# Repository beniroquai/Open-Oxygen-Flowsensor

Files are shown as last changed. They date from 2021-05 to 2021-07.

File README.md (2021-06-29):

# Open Oxygen (O2) Flow Sensor

**WORK IN PROGRESS - more information will follow soon!**

This device is supposed to measure the oxygen flowrate of oxygen bottles.
We would like to have an open-source solution for something like the [TSI digital oxygen flow sensor](https://tsi.com/produkte/durchflussmesser,-durchflusssensoren-testsysteme/die-neuen-digitalen-durchflussmesser-serie-5000/).

<p align="center">
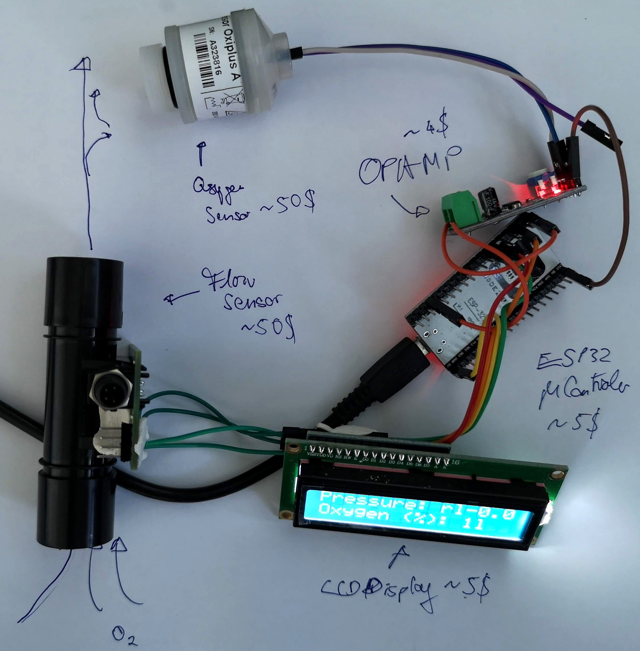
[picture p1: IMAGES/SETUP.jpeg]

</p>

***Features:***

- Open-Source
- Low-Cost (~150€)
- Based on 3D parts + off-the-shelf components
- Minimum of tools required
- Portable by relying on a USB power bank
- LCD for displying oxygen level and flowrate

# Electronics

The flowsensor and the display are connected to the ESP32 via I2C (GPIO 21/22 for SDA/SCL), wheras the Oxygen Sensor is connected to the board via an ampliefied (i.e. OPAMP) digital-analog port.

<p align="center">
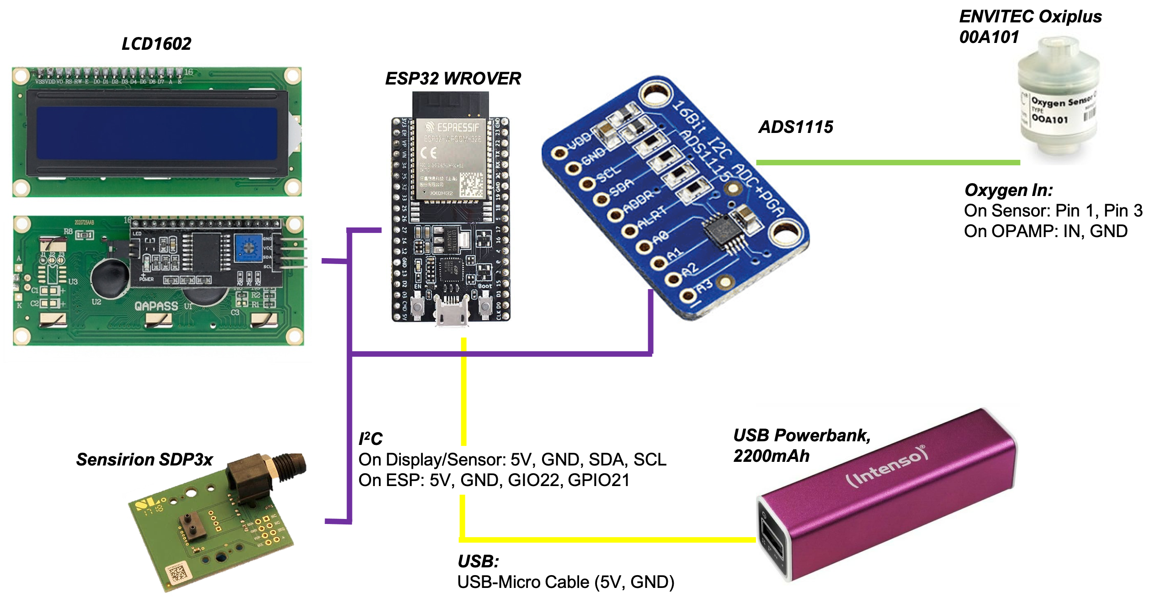
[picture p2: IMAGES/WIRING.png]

</p>

***WARNING:*** The OPAMP has a high-pass filter created by a capacitor + resistor. We need to remove this to let the low-frequency signal from the Oxygen Sensor pass through.

***Solution:*** Instead of relying on the internal ADC converter and have a rather unknwon OPAMP, we decided to go for digital-ADC with a dedicated I2C interface. 
The ADS1115 has 4 channels and a resolution of 16 Bit. 

<p align="center">

</p>

In order to make the device independent from external energy sources, we incorporate a USB-battery/powersupply. We rely on a widely available form factor, where the brand/name of the device can largely vary. 

***Explenation for the ADS1115:*** *Differential* or *Single Ended* use? We have a positive DC-signal in the range of `0...~100mV`, hence we can go for the single-mode use. An in-depth explanation can be found at [Adafruit](https://learn.adafruit.com/adafruit-4-channel-adc-breakouts/signal-connections). The oxygen sensor is then connected to `Pin+ => AD0` and `Pin- => GND`. Running the test-script on the ESP32 should give you a voltage of `13mV` in air. 

# CAD Files

The parts were designed in Autodesk Inventor 2019 student edition and can be found in the folder [./CAD](CAD)
An enclosure/box to keep all parts in place will be 3D printable.

<p align="center">
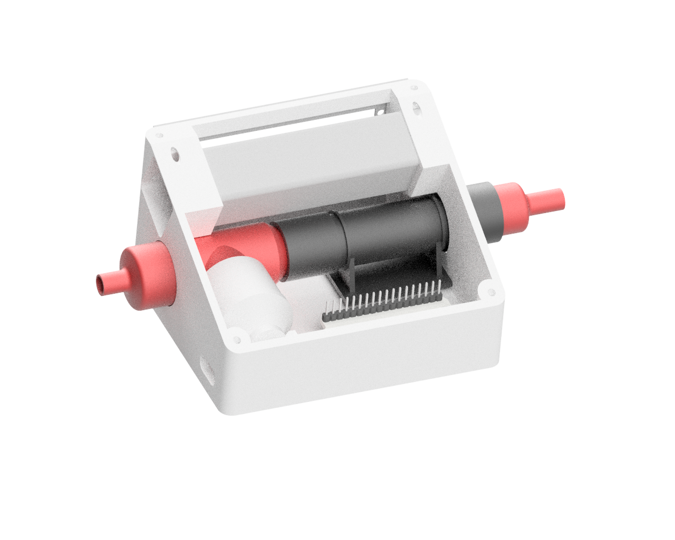
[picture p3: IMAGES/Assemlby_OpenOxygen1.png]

</p>

*Arrangement of all the parts*

## Housing for the setup

The setup will have a housing for all the parts. Currently it looks like this, where the battery is sitting on top:

<p align="center">
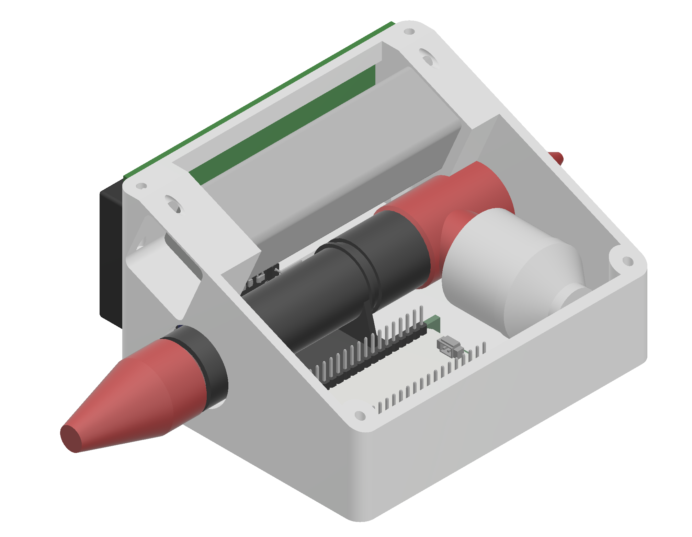
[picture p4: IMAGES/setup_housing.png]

</p>

*Arrangement of all the parts*

<p align="center">
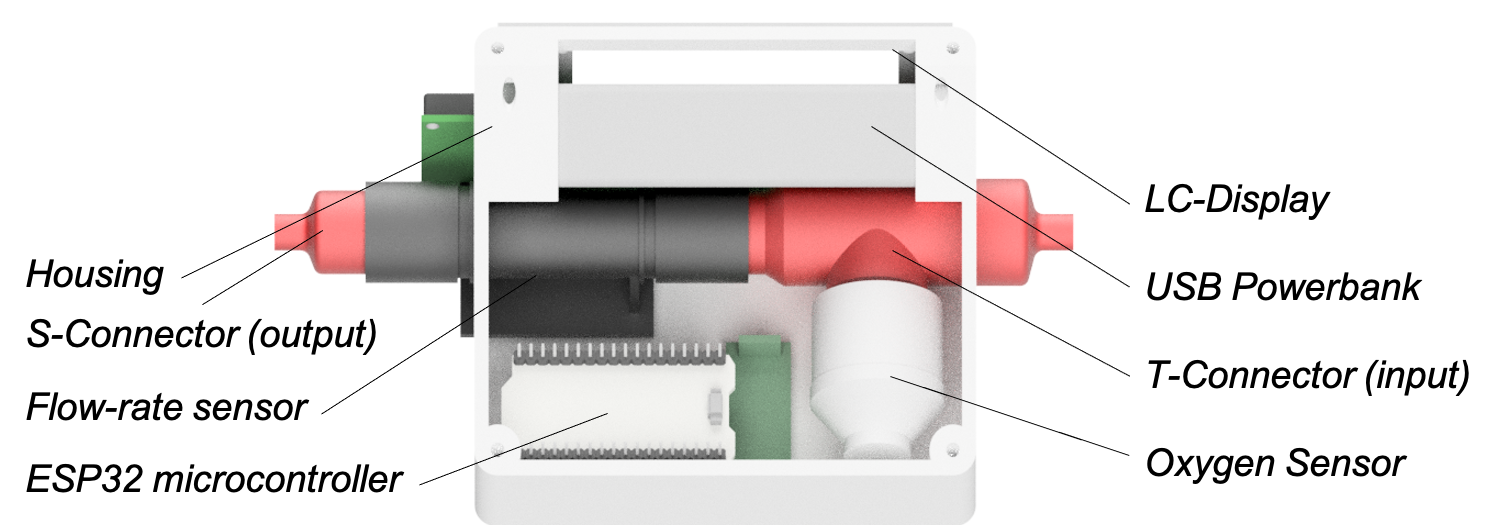
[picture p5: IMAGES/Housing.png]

</p>

All **3D printable** files can be found in [./STL](./STL)

# Assembly

*Sorry for the confusion:* You can mount the parts in both directions. Here, the CAD rendering shows the oxygen sensor on the right hand side, whereas the printed version shows it on the right hand side. Either way works!

1. Make sure you solder all parts together according to the wiring diagram above; To keep the wire chaos small: Twist the cables to form wire bundles; Test its proper functionality by e.g. running the [I2C scanner in the Arduino IDE](https://playground.arduino.cc/Main/I2cScanner/) (you must detect 3 addresses); Then flash the firmware in the Arduino folder.  ***HINT:*** There are some libraries involved; Please install them from the library downloader menu as described [here](https://www.arduino.cc/en/guide/libraries). The following libraries are used: `LiquidCrystal_I2C by Brabander`, `Sparkfun SDP3X by Sparkfun`, and `Adafruit ADS1X15`.
2. Place the LCD screen on the front plate and mount it with 4 M3x12 screws 
3. Place the flow-rate sensor (sensirion) on the plate by pushing one end through one of the wholes. Watch the photograph:

<p align="center">
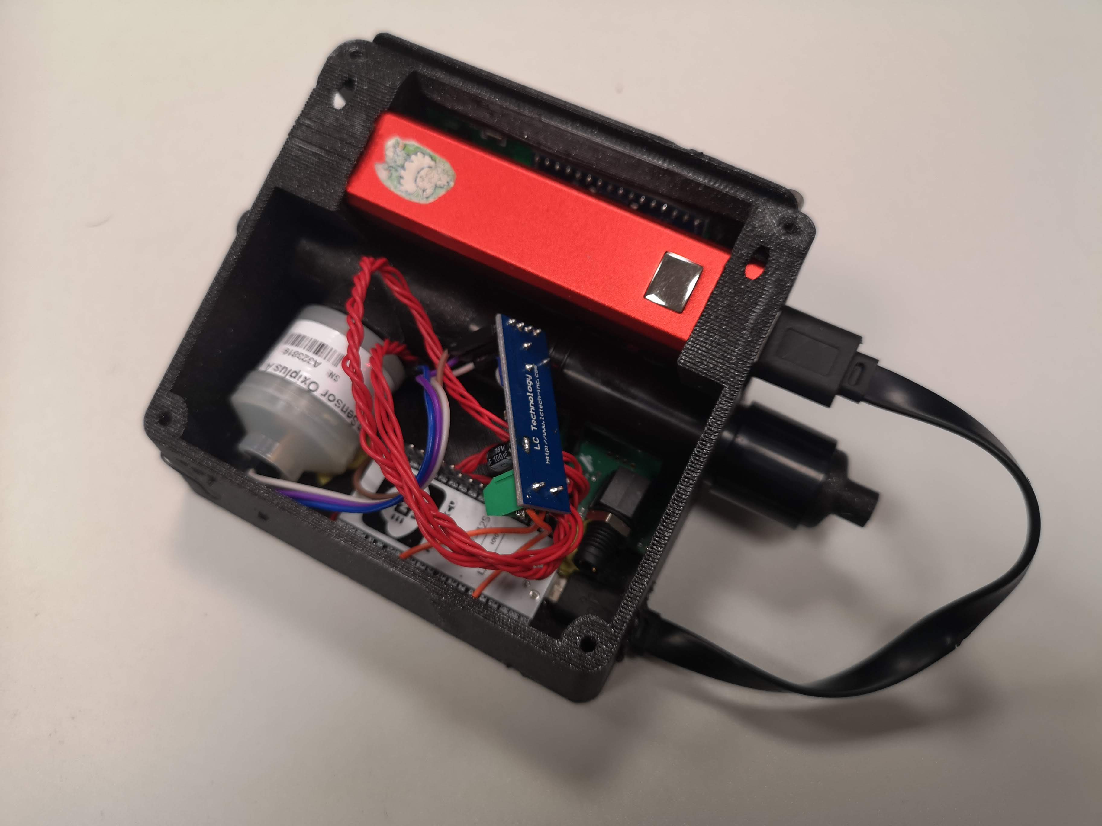
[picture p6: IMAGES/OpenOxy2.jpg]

</p>

4. Now mount the S-connector to the outside of the injection moulded flow adapter (black plastic part of the sensirion); Beware: We don't mount the flow sensor permanently 
5. Mount the T-connector (tricky part, not much space); push the black flow adaptor at a side (e.g. diagonal) and try sneaking in the T-adaptor; Move the one thin end into the hole of the Flow sensor
6. Mount the Oxygen sensor to the open end of the T-connector inside the case 
7. Rotate the oxygen sensor the way that it resides on the base plate 
8. Place the ESP32 in the free spot on the base (no holes for screws, since the formfactor is largely varying!) 
9. Place the OPAMP in the assembly; make sure the open pin connects will **never** cause any shortcut!
10. Mount the LCD Screen using additional M3 screws:

<p align="center">
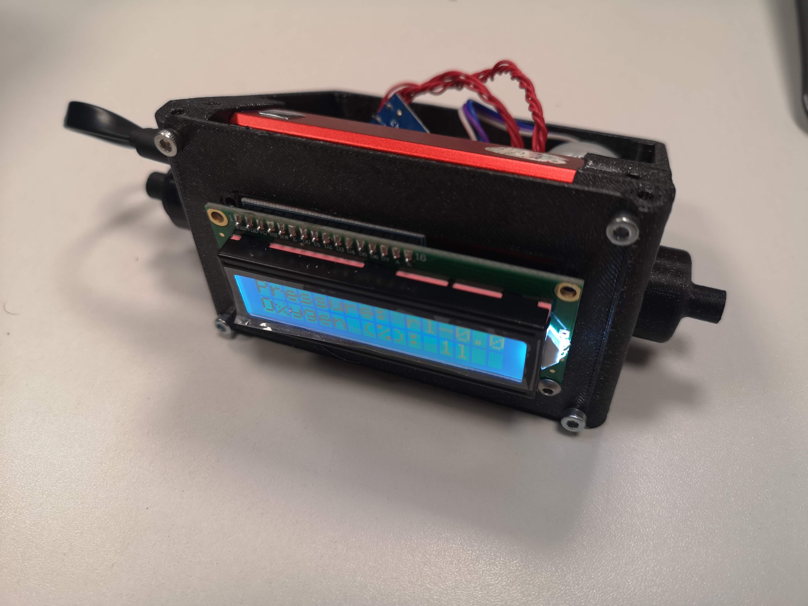
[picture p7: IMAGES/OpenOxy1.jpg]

</p>

11. Add the Powerbank in the desired slot and also add the USB Micro cable
<p align="center">
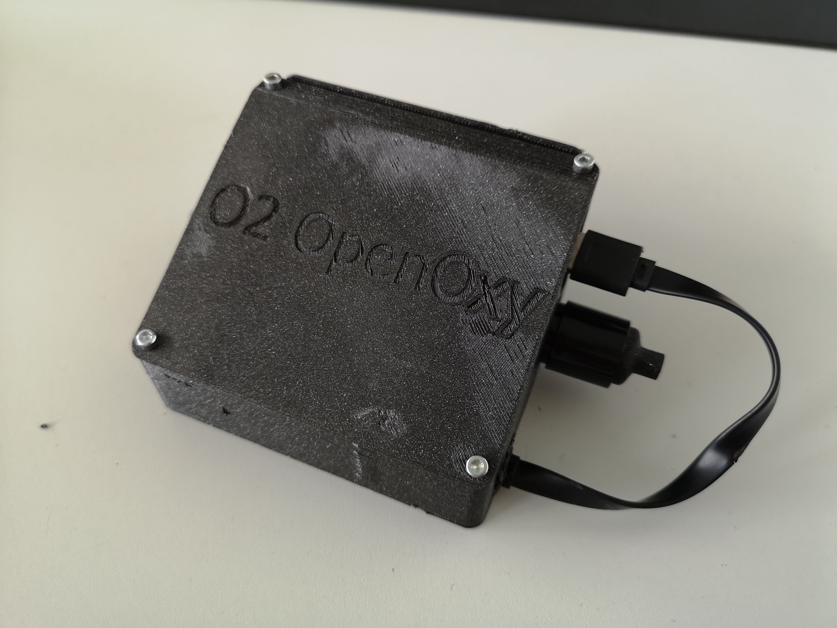
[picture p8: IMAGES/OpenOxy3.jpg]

</p>

12. Add the lid and mount it using M3 screws 
<p align="center">
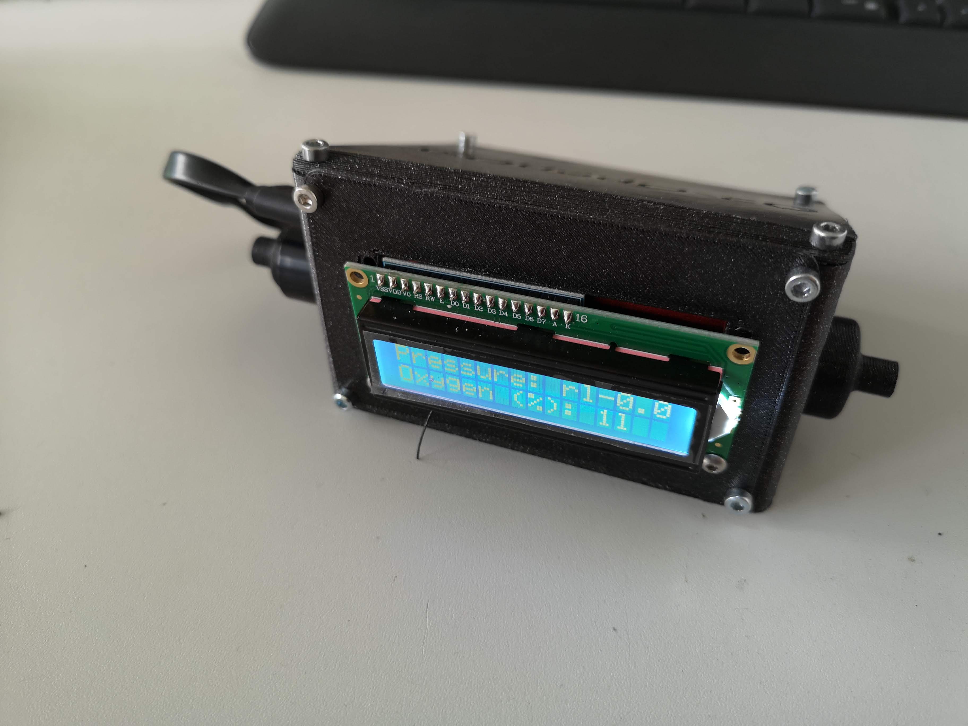
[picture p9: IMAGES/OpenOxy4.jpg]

</p>

13. You are done! If you want to have the assembly working under an anble, you can simply rotate the screen: 

<p align="center">
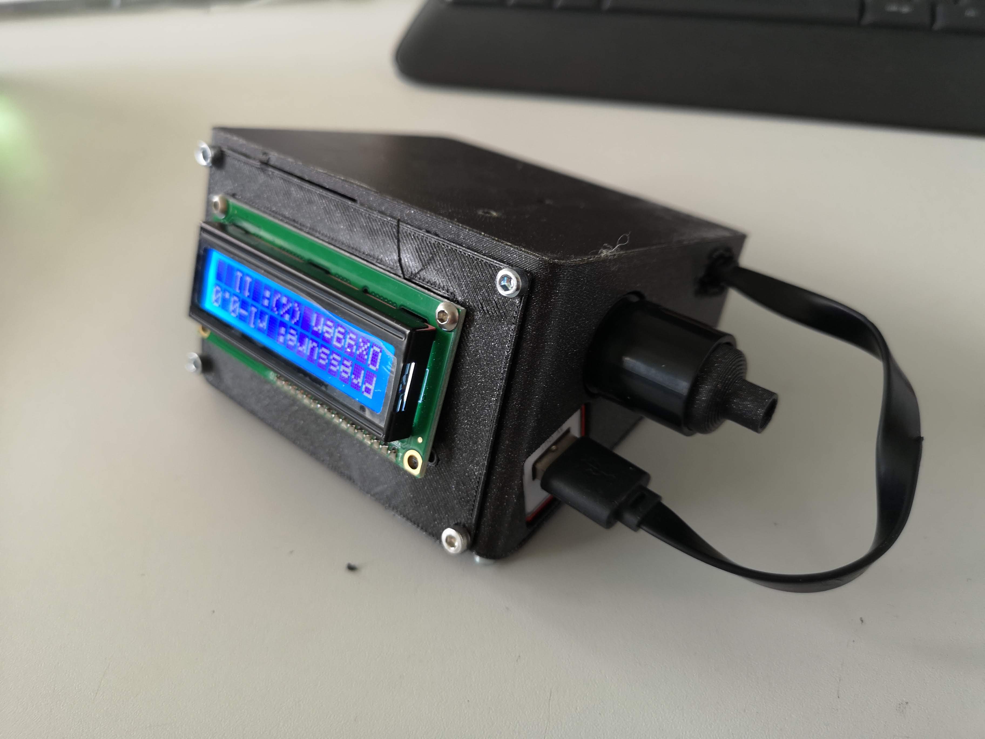
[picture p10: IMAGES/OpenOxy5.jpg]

</p>

# Software

A first attempt to connect all components can be found in [./ARDUINO](./ARDUINO) (even though it's used by an ESP32, flash it in the Arduino IDE).

## Calibration

### Calibration of the air flow

The [datasheet](Sensirion_Differential_Pressure_AppNotes_EK-P4_Flow_Element.pdf) for the Sensirion EK-P4 Evaluation Kit
For SDP3x Flow sensor suggests a relationship between differential pressure and flow-rate measured in Standard Liters per Minute (slm). We fit a curve to the values given in the application note in order to have a parametrized function for the digital readout:

<p align="center">
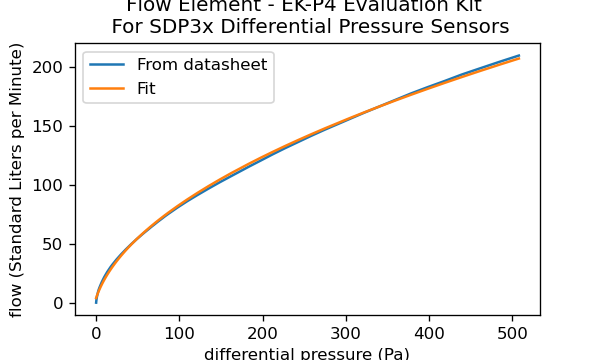
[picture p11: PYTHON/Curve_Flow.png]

</p>

The corresponding Python script to generate this figure can be found [here](PYTHON/Fit_Flow_Calibration_Function.py). 

The fit suggest the following function: 

```py
def func(x, a, b, c, d):
    return a+np.sqrt(b+x*d)*c

a=-20.04843438
b=59.52168936
c=3.11050553
d=10.35186327
```

which can easily be implemented on the ESP32. 

Use previously measured calibration data? 

### Calibration of the oxygen level (automatic)

By default, the current implementation will automatically calibrate the initial voltage of the oxygen sensor to correspond to 20.9% O2 level. This calibration will take place 10 seconds after starting the device.

### Calibration of the oxygen level (manual)

The oxygen sensor has a voltage of ~11mV in air, coresopnding to 20.9% O2 level. Placing the whole device in a oxygen-free enivornment (e.g. dry ice), gives a signal from ~3mV. This information can be used to fit a curve and compute the parameters for the linear fit (~3% error according to the manual/datasheet). 

<p align="center">
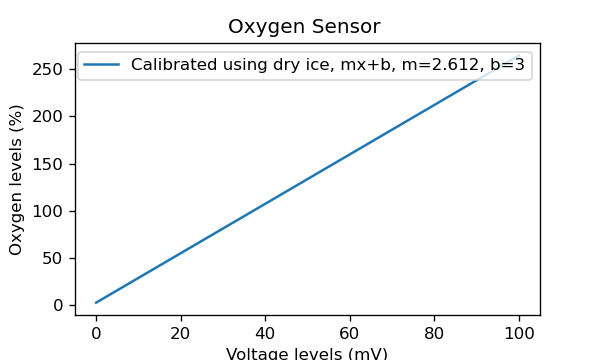
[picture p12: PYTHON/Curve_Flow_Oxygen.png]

</p>

The corresponding Python script to generate this figure can be found [here](PYTHON/Fit_Flow_Calibration_Function.py) and gives these values:
```py
m,b
2.6125 3
```

which have to be entered in the code `OpenOxygenFlowMeter.ino` in the folder [ARDUINO](./ARDUINO)
```cpp
float oxy_m = 2.62; // needs to be calibrated
float oxy_b = 3;  // needs to be calibrated (corresponds to the voltage at Oxygen level == 0%)
```

In order to prevent `oxy_m` from being auto calibrated, automatic calibration needs to be disabled by setting `boolean shouldDoWarmupCalibration = false;`.

# Bill of materials

- Misc Wires for connecting all parts (use proper soldered connection!)
- USB micro Cable for flashing the firmware and for supplying energy for portable-mode
- Various M3 Cylindrical Screws, M3x12mm, 1€ 
- [I2C LCD Display](https://de.aliexpress.com/item/32413056677.html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,searchweb201602_,searchweb201603_), **1,82€**
- [ads1115 Analog Digital Converter, 16Bit, I2C Breakoutboard](https://de.aliexpress.com/item/32584944400.html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) (Need to be tested); **2,32€**
- [ESP32](https://de.aliexpress.com/item/1005002624723822.html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,searchweb201602_,searchweb201603_), **4,01€**
- [oxygen sensor oxiplus a 00a101](https://de.aliexpress.com/item/4000133941125.html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,searchweb201602_,searchweb201603_); **50,01€**, [Datasheet](https://www.was-geisler.biz/WEBSERVER/Bausteine/Dateien/DB_AU-007_008.pdf)
- [Sensirion Evaluationskit EK-P4, SDP3X](https://www.digikey.de/product-detail/de/sensirion-ag/EK-P4/1649-1059-ND/6109354?productid=6109354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); **50,10€**, [Datasheet](https://www.sensirion.com/en/flow-sensors/differential-pressure-sensors/test-your-sdp3x-differential-pressure-sensor-with-the-evaluation-kit-ek-p4/)
- [USB Powerbank, 5V, 2200mAh (make sure, the battery looks like the one above!)](https://www.ebay.de/p/1437454225); **2,10€**, The brand can vary, but make sure it's fitting in the housing)

# Contribute
If you have a question or found an error, please file an issue! We are happy to improve the device!

# License
Please have a look into the dedicated License file.

# Disclaimer
We do not give any guarantee for the proposed setup. Please use it at your own risk. Keep in mind that Laser source can be very harmful to your eye and your environemnt! It is not supposed to be used as a medical device!

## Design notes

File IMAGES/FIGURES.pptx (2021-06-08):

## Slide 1

LCD1602

ENVITEC Oxiplus
00A101

Oxygen In:
On Sensor: Pin 1, Pin 3
On OPAMP: IN, GND

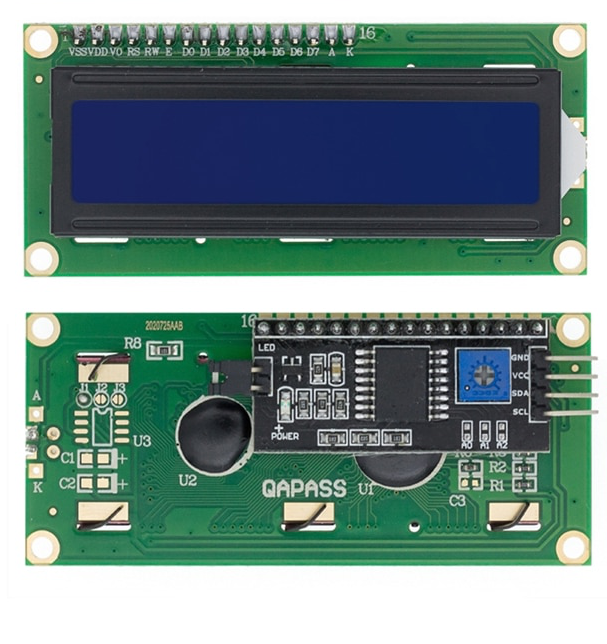
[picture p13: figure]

ESP32 WROVER

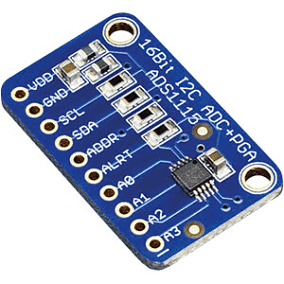
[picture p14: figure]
Entwicklerboards - A/D-Verstärker-Platine, 16-Bit, ADS1115 - DEBO AMP 16BIT
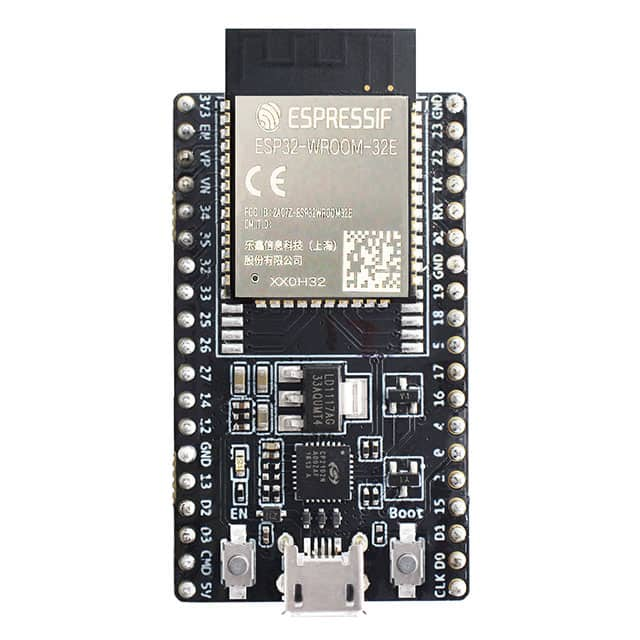
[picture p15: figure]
ESP32-DEVKITC-32E Espressif Systems | HF/ZF und RFID | DigiKey

ADS1115

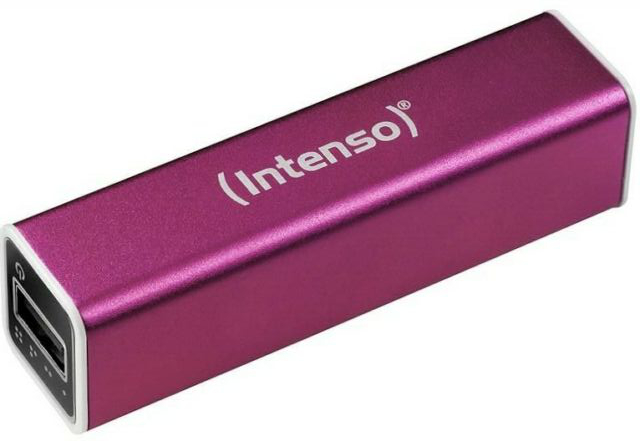
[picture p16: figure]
Bild 3 von 4

USB Powerbank,
2200mAh

Sensirion SDP3x

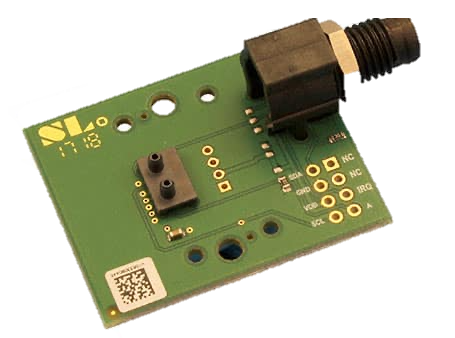
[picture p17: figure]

I²C
On Display/Sensor: 5V, GND, SDA, SCL
On ESP: 5V, GND, GIO22, GPIO21

USB:
USB-Micro Cable (5V, GND)

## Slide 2

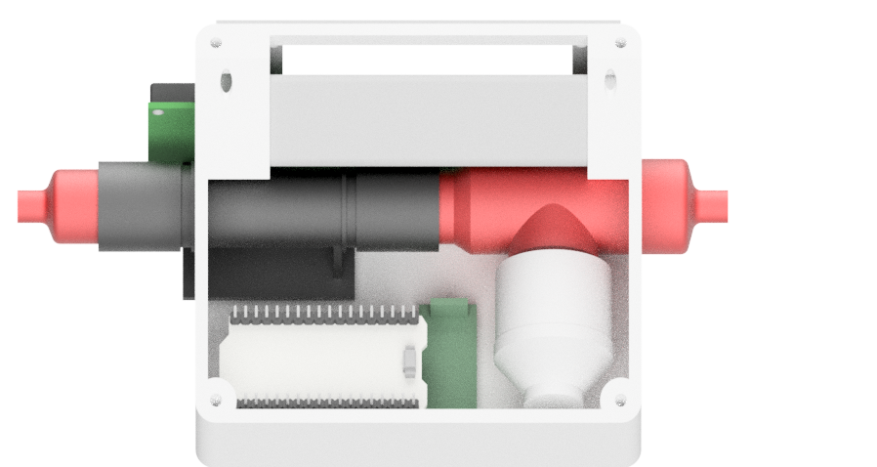
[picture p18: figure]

Housing

LC-Display

USB Powerbank

S-Connector (output)

T-Connector (input)

Flow-rate sensor

ESP32 microcontroller

Oxygen Sensor

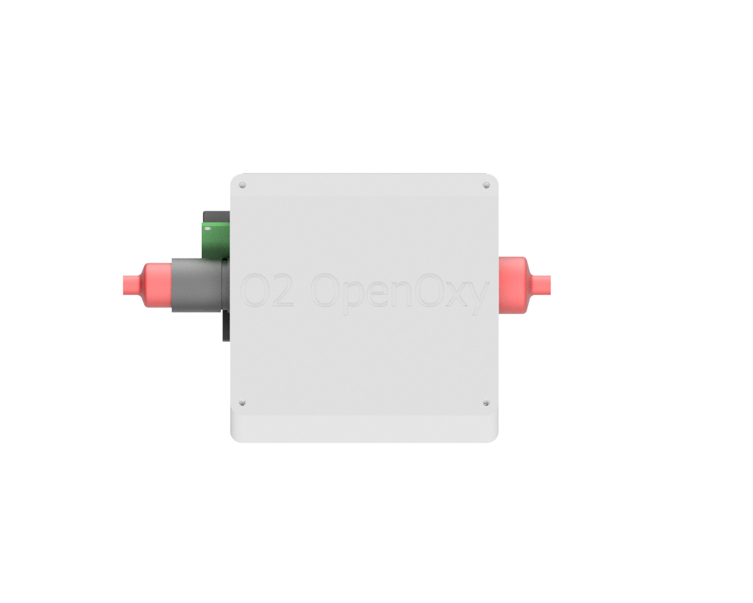
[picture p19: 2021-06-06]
IMAGES/Assemlby_OpenOxygen.png

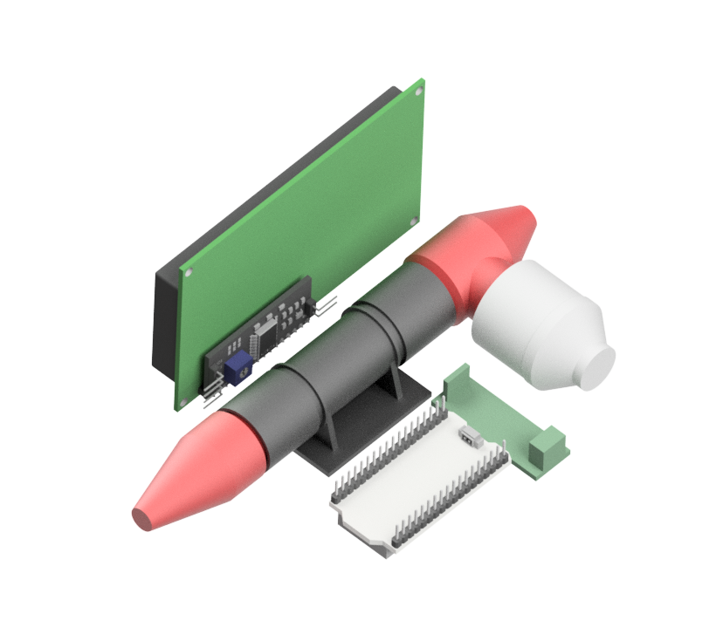
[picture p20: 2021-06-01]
IMAGES/image.png

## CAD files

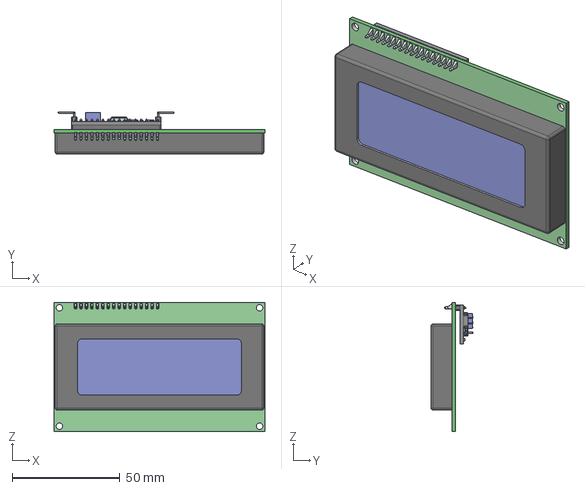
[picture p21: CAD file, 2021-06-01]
INVENTOR/00_Arduino_LCD_I2Cstep.step
98.0 x 19.6 x 60.0 mm

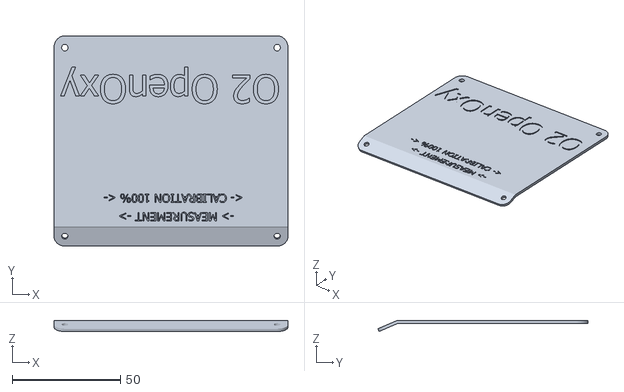
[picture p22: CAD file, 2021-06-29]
STL/Assemlby_OpenOxygen_02_03_Lid.stl
108.0 x 97.0 x 5.08

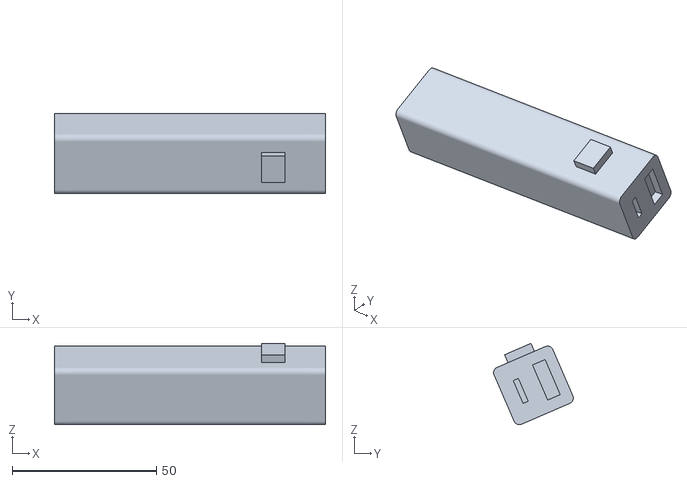
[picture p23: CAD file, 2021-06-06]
STL/NON-printable/Assemlby_OpenOxygen_00_Batterypack.stl
94.0 x 27.7 x 28.2

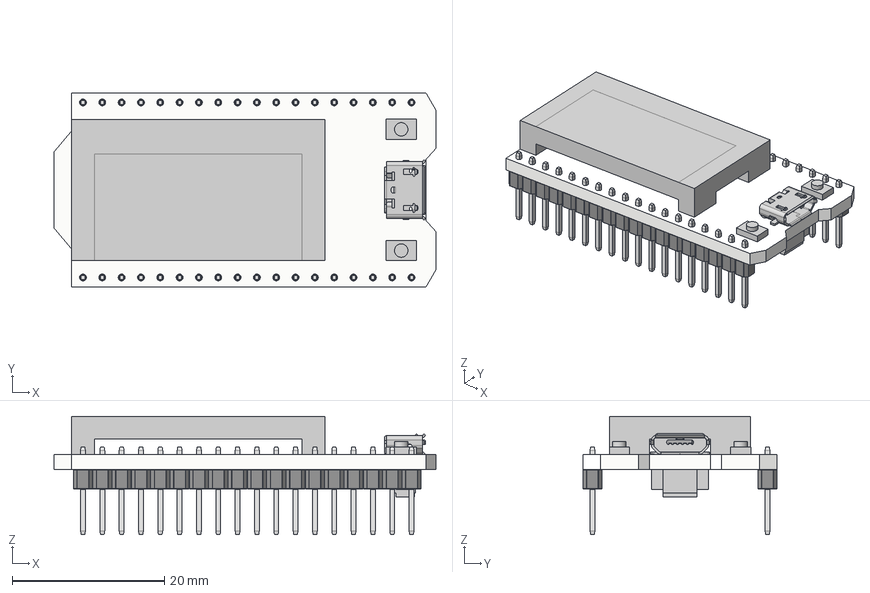
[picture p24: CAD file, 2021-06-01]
INVENTOR/00_ESP32.step
50.2 x 25.5 x 15.5 mm
Micro-USB Cable socket
SH1.25-2
1 Pin 2.54 Header x 36

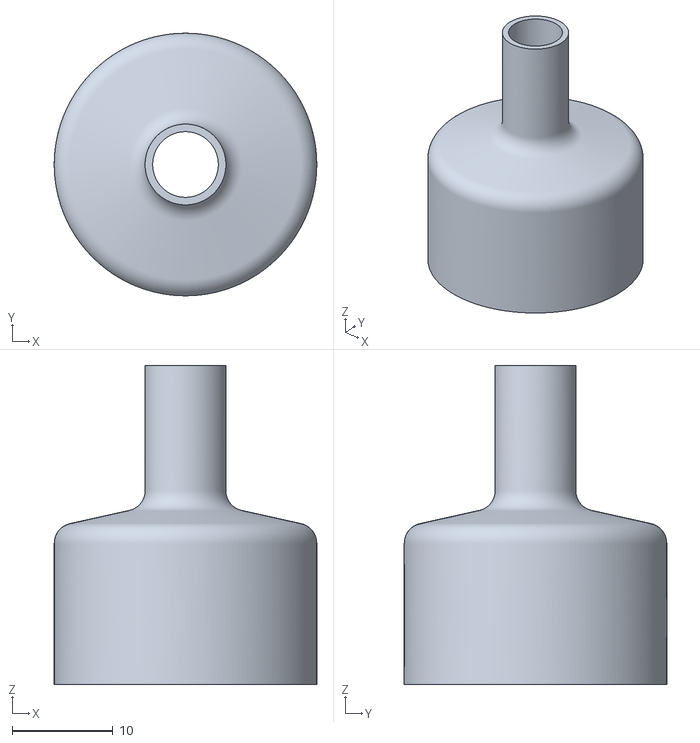
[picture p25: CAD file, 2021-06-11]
STL/Assemlby_OpenOxygen_02_Connector_S.stl
26.0 x 26.0 x 31.6

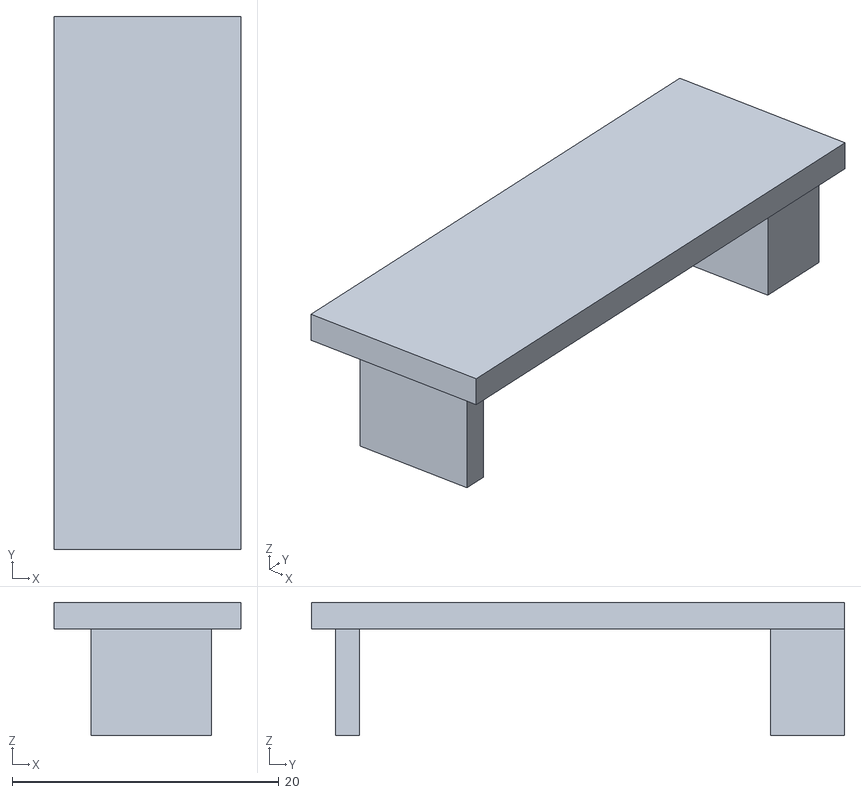
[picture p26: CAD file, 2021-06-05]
STL/NON-printable/Assemlby_OpenOxygen_00_LM286.stl
14.0 x 40.0 x 10.0

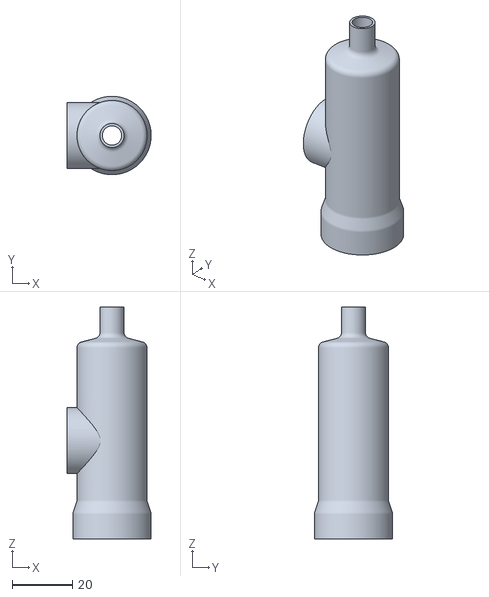
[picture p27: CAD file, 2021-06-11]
STL/Assemlby_OpenOxygen_02_Connector_T.stl
28.0 x 26.0 x 77.0

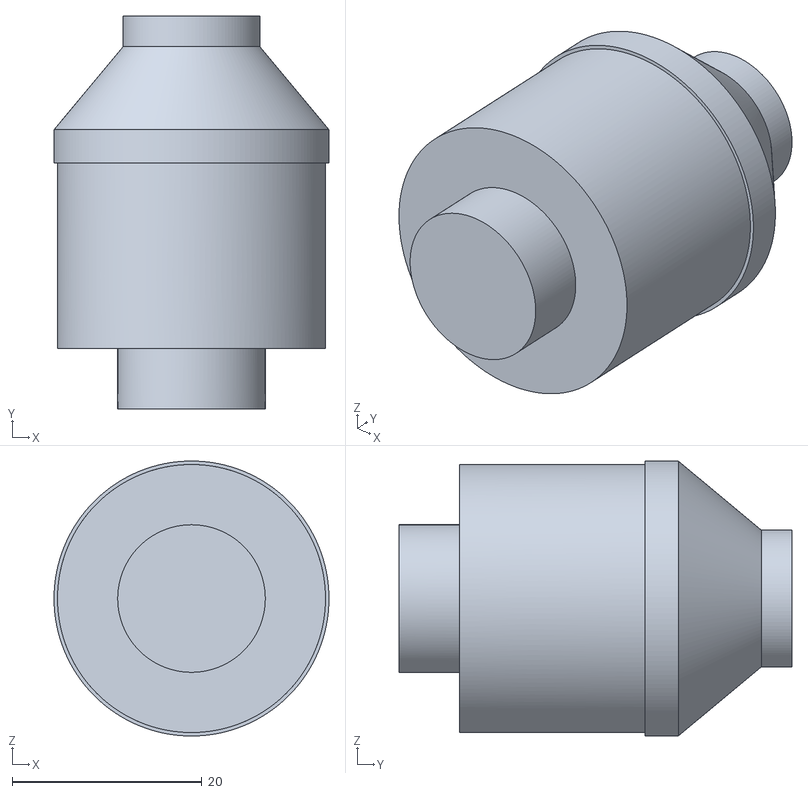
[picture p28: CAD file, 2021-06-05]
STL/NON-printable/Assemlby_OpenOxygen_00_Oxygen_Oxi.stl
29.0 x 41.4 x 29.0

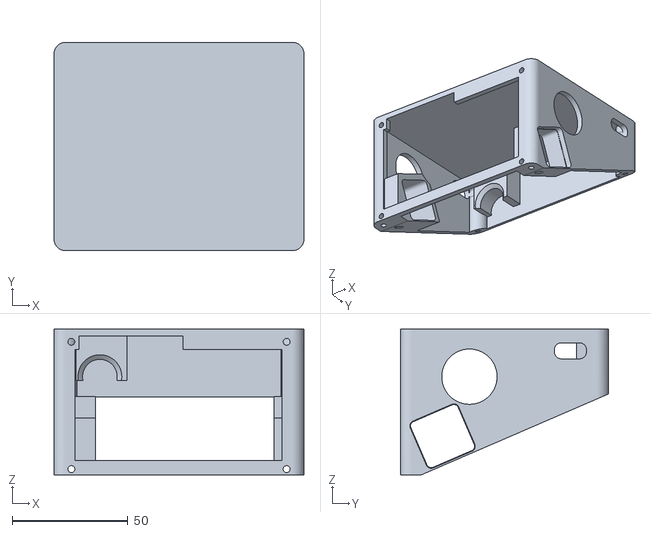
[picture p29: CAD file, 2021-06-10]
STL/Assemlby_OpenOxygen_03_OpenOxygen_Box.stl
108.0 x 90.0 x 63.0

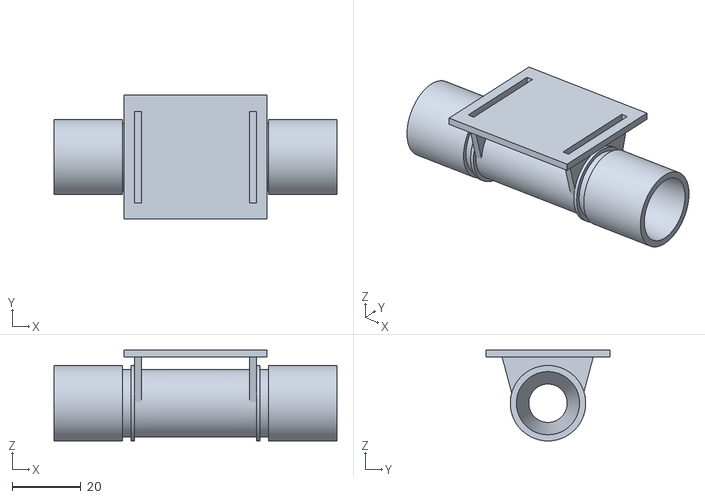
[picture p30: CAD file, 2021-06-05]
STL/NON-printable/Assemlby_OpenOxygen_00_Sensirion_Flowsensor.stl
82.5 x 36.1 x 26.5

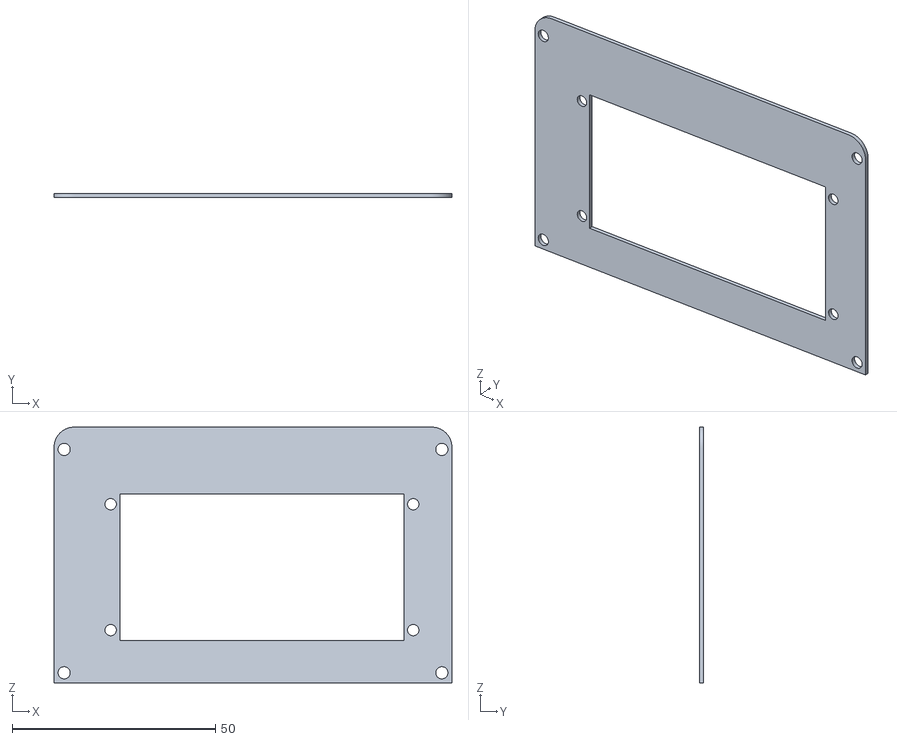
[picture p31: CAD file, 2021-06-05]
STL/Assemlby_OpenOxygen_04_Adapterplate_Display.stl
98.0 x 1.00 x 63.0

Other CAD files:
INVENTOR/00_Arduino_LCD_I2Cstep.ipt
INVENTOR/00_Batterypack.ipt
INVENTOR/00_ESP32.ipt
INVENTOR/00_LM286.ipt
INVENTOR/00_Oxygen_Oxi.ipt
INVENTOR/00_Sensirion_Flowsensor.ipt
INVENTOR/02_Connector_S.ipt
INVENTOR/02_Connector_T.ipt
INVENTOR/03_Lid.ipt
INVENTOR/03_OpenOxygen_Box.ipt
INVENTOR/04_Adapterplate_Display.ipt
INVENTOR/Assemlby_OpenOxygen.iam
INVENTOR/OldVersions/00_LM286.0001.ipt
INVENTOR/OldVersions/00_Oxygen_Oxi.0001.ipt
INVENTOR/OldVersions/00_Sensirion_Flowsensor.0003.ipt
INVENTOR/OldVersions/01_Connector_T.0004.ipt
INVENTOR/OldVersions/02_Connector_S.0009.ipt
INVENTOR/OldVersions/02_Connector_T.0008.ipt
INVENTOR/OldVersions/03_Lid.0002.ipt
INVENTOR/OldVersions/03_OpenOxygen_Box.0009.ipt
INVENTOR/OldVersions/Assemlby_OpenOxygen.0015.iam

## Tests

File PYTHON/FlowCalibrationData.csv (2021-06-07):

DP (Pa) | Flow (slm)
0 | 0
0.15 | 1.1
0.32 | 2.1
0.54 | 3.2
0.79 | 4.3
1.07 | 5.4
1.39 | 6.4
1.75 | 7.5
2.13 | 8.6
2.52 | 9.7
2.93 | 10.7
4.08 | 12.9
5.32 | 15
6.65 | 17.2
8.09 | 19.3
9.65 | 21.5
11.35 | 23.6
13.18 | 25.8
15.15 | 27.9
17.26 | 30.1
19.51 | 32.2
21.92 | 34.3
24.43 | 36.5
27.07 | 38.6
29.84 | 40.8
32.71 | 42.9
35.7 | 45.1
38.76 | 47.2
41.94 | 49.4
45.21 | 51.5
48.59 | 53.7
52.06 | 55.8
55.62 | 58
59.24 | 60.1
62.92 | 62.2
66.67 | 64.4
70.48 | 66.5
74.38 | 68.7
78.35 | 70.8
82.38 | 73
86.52 | 75.1
97.57 | 80.5
109.38 | 85.9
121.82 | 91.2
134.98 | 96.6
148.59 | 102
162.57 | 107.3
183.3 | 115.1
197.59 | 120.3
212.03 | 125.6
226.9 | 130.8
242.51 | 136
258.42 | 141.3
274.74 | 146.5
304.68 | 155.6
322.5 | 161
340.83 | 166.3
359.43 | 171.7
378.05 | 177.1
397.91 | 182.4
419.05 | 187.8
439.32 | 193.2
461.5 | 198.5
484.33 | 203.9
507.99 | 209.3

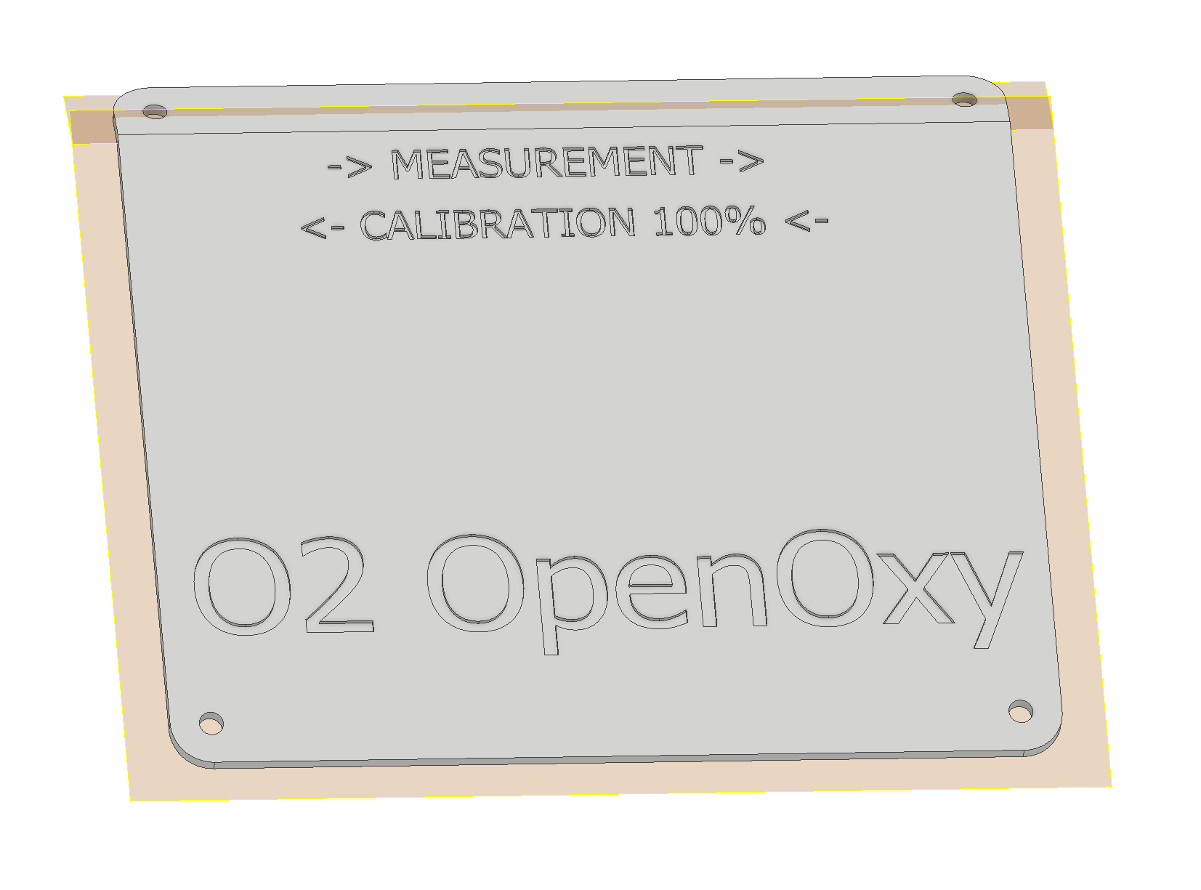
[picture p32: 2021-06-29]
IMAGES/LidCalibration.PNG

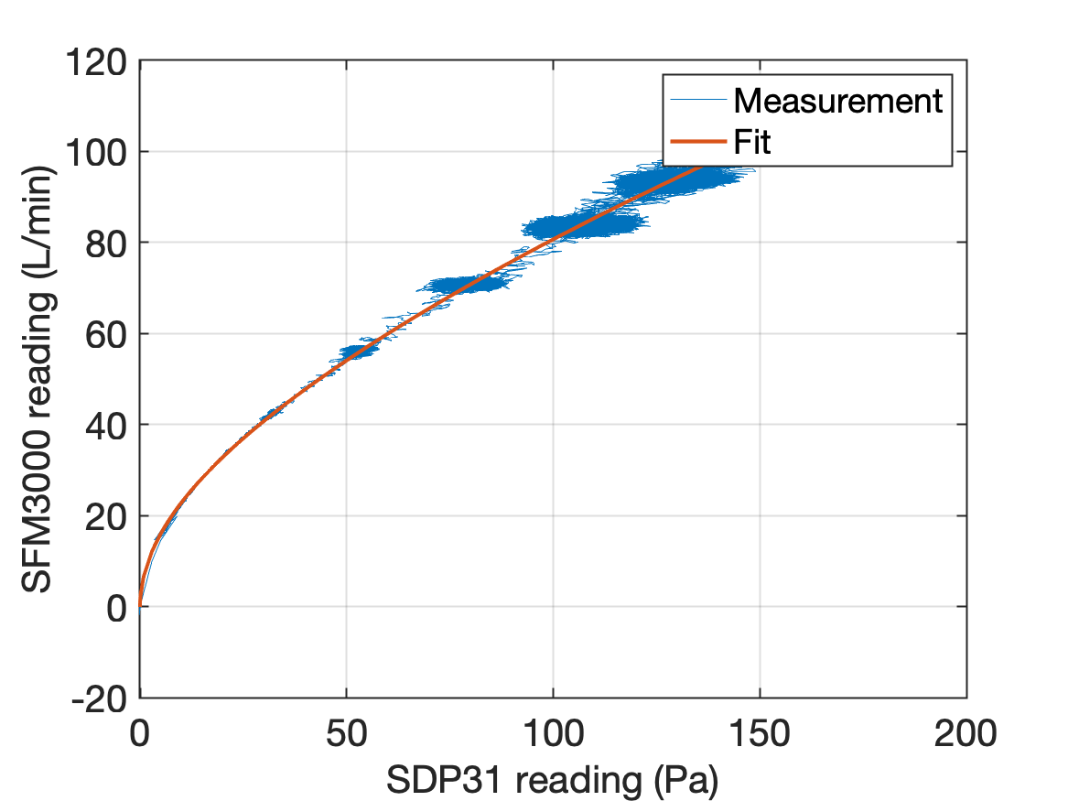
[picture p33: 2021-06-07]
PYTHON/calibration.png

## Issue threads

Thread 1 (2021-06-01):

Creating a proper housing for the Assembly

beniroquai, 2021-06-01:
- [ ] Easily printable
- [ ] Maximum two parts
- [ ] Openings for inlets/outlets (air) + charging
- [ ] Robust
- [ ] Perhaps a tube?

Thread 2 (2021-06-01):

Procedure for calibrating the Oxygen sensor?

beniroquai, 2021-06-01:
# Idea:

- Have a two-point calibration procedure (no oxygen => O2=0%) vs. air (21%)
- Trigger calibration through GUI running on the ESP32 webserver or mechanical button? Restore?

mahip-nicn, 2021-06-06:
Adding more ideas :)

- If the sensor has been through span-calibration after production, a single-point calibration (20.9 %)  at standard air should be enough.  [Source.](https://gaslab.com/blogs/articles/gas-sensor-calibration)
- Can a 3-point calibration/cross-validation graph be used? Assuming medical O2 cylinders give purity ~ 97% (the 3rd point). Maybe these 3 points can test the oxygen sensor right off the box? Then, do a single-point test (20.9%) for most O2 analyzers. O2 Cylinder's availability should not be an issue?

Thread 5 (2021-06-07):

Procedure for calibrating the device - at air

beniroquai, 2021-06-07:
Have a button that can be pressed (long button press), to calibrate the device using air (20.9%)

subirbhaduri, 2021-06-14:
Hi Benedict. For calibration in a frugal setting like in India where dry ice would not be available, could you place the device into a small chamber with a burning candle? If the chamber is closed, the candle consumes all O2 (or most of it) and will give some zero reference for your device. Not sure if this is a good idea to get zero reference.

beniroquai, 2021-06-14:
Hey, thanks for your comment! We already investigated this idea. The problem with this is, that the candle is made out of paraffin which will not only produce CO2 while burning. Also, there will always be a rest amount of O2 in the box.
Manu and Honquan Li suggested using 100% as a reference. Alternatively, do you know if these gas cylinders are available in India?

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

Alternatively, we may think of having sparkling water bottles? Not sure if this could work..

subirbhaduri, 2021-06-14:
Oh ya, that could be an issue. Maybe sparkling water is not available in
India, but Coke and Pepsi are, and i guess the gas embedded is CO2. However
how can you expose the sensor to a CO2 laden liquid?? Don't know, lets
think.

On Mon, Jun 14, 2021 at 10:36 AM Benedict Diederich <
***@***.***> wrote:

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

subirbhaduri, 2021-06-14:
O2 bottles may also be widely available, and can be used just for
calibration if the calibration does not change over say a period of 1 month
or something like that.

On Mon, Jun 14, 2021 at 5:58 PM Subir Bhaduri ***@***.***>
wrote:

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

beniroquai, 2021-06-14:
For this we can build a 3D printed adapter.

>

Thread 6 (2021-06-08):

Output of the Oxygen sensor is noisy

beniroquai, 2021-06-08:
It appears, that the output of the oxygen sensor needs to be denoised.

beniroquai, 2021-06-08:
Response of the sensor by opening a water bottle and placing the sensor in the H2Co3 flow:

(polarity was inverted)
Base level at pure air is ~11mV

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

beniroquai, 2021-06-13:
This does not seem to be a problem with the analog-digital converter [ADS1115](http://cool-web.de/esp8266-esp32/ads1115-16bit-adc-am-esp32-voltmeter.htm) used by the ESP32.

Closed 2021-06-13.

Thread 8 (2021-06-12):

Lid STL location

frauzufall, 2021-06-12:
I can't find the STL file of the lid of the box, is it missing?

beniroquai, 2021-06-13:
Solved in latest commit #e72a11c.
Sorry for missing that file ;-)

beniroquai, 2021-06-13:
# # #

frauzufall, 2021-06-13:
Thanks!! :raised_hands:

Closed 2021-06-13.

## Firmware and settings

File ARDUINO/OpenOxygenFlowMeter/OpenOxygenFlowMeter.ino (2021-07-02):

#include <LiquidCrystal_I2C.h>
#include <SparkFun_SDP3x_Arduino_Library.h> // Click here to get the library: http://librarymanager/All#SparkFun_SDP3x
#include <Wire.h>
#include <Adafruit_ADS1015.h>//#include <Adafruit_ADS1X15.h> // Does not work on Windows :/ 
#include <Preferences.h>

/* HARDWARE */

// all connected to I2C: SDA: Pin 21, SCL: 22
SDP3X mySensor; //create an object of the SDP3X class
Adafruit_ADS1115 ads;  /* Use for the oxygensensor */
LiquidCrystal_I2C lcd(0x38, 16, 2); // set the LCD address to 0x3F for a 16 chars and 2 line display

/* CONFIGURABLE VALUES */

float oxy_m = 2.62; // needs to be calibrated
float oxy_b = 3;  // needs to be calibrated (corresponds to the voltage at Oxygen level == 0%)
static float airCalibrationValue = 20.9;
static float negativeFlowCalibrationValue = 100; // change this value to adjust the target oxygen concentration during negative flow calibration
float minAbsDiffPressure = 10; // needs to be calibrated (minimal absolute value of pressure to trigger negative flow calibration)

/* CONFIGURABLE BEHAVIOUR */

boolean shouldDoWarmupCalibration = true; //change this to false to skip warmup / calibration phase

/* CONFIGURABLE DELAYS */

unsigned static long warmupDelayInMs = 1000 * 10; // 10s warmup time before calibrating to 21% oxygen level
unsigned static long negativeFlowInitDelayInMs = 1000 * 2; // 2s before initiating negative flow calibration
unsigned static long calibrateNegativeFlowWarmupInMs = 1000 * 10; // 10s warmup time before negative flow calibration
unsigned static long negativeFlowPermanentSaveDelayInMs = 1000 * 10; // 10s delay before storing negative flow calibration value permanently

/* NON CONFIGURABLE */

int16_t adc0 = -1;
int16_t mv = 0;
float adcToMV =  0.1875;
unsigned long startTime;
unsigned long negativeFlowStartTime = 0;

struct CalibrationPoint {
  float oxygenLevel;
  float voltage; // in mV
};

CalibrationPoint calibrationA;
CalibrationPoint calibrationB;

unsigned static long infoMsgDelay = 1000 * 2; // 2s delay to display an info message

uint8_t countdown = 0;

float flowRate = 0;
float diffPressure = 0;
float oxygenLevel = 0;
float oxygenVoltageAtLaunch = 0;

enum DeviceState {
  LAUNCH,
  RESTORE_CALIBRATION,
  CALIBRATION_AIR_WARMUP,
  CALIBRATION_AIR,
  MEASURING,
  CALIBRATION_NEGFLOW_WARMUP,
  CALIBRATION_NEGFLOW_DONE,
  CALIBRATION_NEGFLOW_SAVE_DELAY,
  CALIBRATION_NEGFLOW_SAVED
};

enum DeviceState state = LAUNCH;

Preferences prefs;
const char* prefsDevice = "openOxy";
const char* prefsM = "m";
const char* prefsB = "b";


// TODO: Need to add a button to start the calibration
void setup() {

  Serial.begin(115200);

  Serial.println("Open Oxygen starting..");

  Wire.begin();

  // Initialize sensor
  mySensor.stopContinuousMeasurement();
  if (mySensor.begin() == false)
  {
    Serial.println(F("SDP3X not detected. Check connections. Freezing..."));
    while (1)
      ; // Do nothing more
  }
  mySensor.startContinuousMeasurement(true, true); // Request continuous measurements with mass flow temperature compensation and with averaging
  delay(1);

  // oxygen sensor related
  ads.setGain(GAIN_TWOTHIRDS);  // 2/3x gain +/- 6.144V  1 bit = 3mV      0.1875mV (default)
  ads.begin();
  // Setup 3V comparator on channel 0
  ads.startComparator_SingleEnded(0, 1000);


  // Init display
  lcd.init();
  lcd.clear();
  lcd.backlight();
  lcd.setCursor(2, 1);
  lcd.print("     O2       ");
  lcd.setCursor(2, 0);
  lcd.print("Open Oxygen");

  // initial calibration points at zero and ambient
  calibrationA.oxygenLevel = airCalibrationValue;
  calibrationA.voltage = (airCalibrationValue - oxy_b) / oxy_m;
  calibrationB.oxygenLevel = 0;
  calibrationB.voltage = oxy_b;

  // set initial value for ambient voltage to something reasonable in case warmup is set to be skipped
  oxygenVoltageAtLaunch = calibrationA.voltage;

  if (!shouldDoWarmupCalibration) {
    state = MEASURING;
  }

  // read initial calibration values from flash
  if (openPreferences(true)) {
    float flashM = prefs.getFloat(prefsM, -1);
    float flashB = prefs.getFloat(prefsB, -1);
    Serial.print("Reading initial oxy_m value from flash: ");
    Serial.println(flashM);
    Serial.print("Reading initial oxy_b value from flash: ");
    Serial.println(flashB);
    if (flashM > -1 && flashB > -1) {
      oxy_m = flashM;
      oxy_b = flashB;
      calibrationA.voltage = (calibrationA.oxygenLevel - oxy_b) / oxy_m;
      calibrationB.voltage = (calibrationB.oxygenLevel - oxy_b) / oxy_m;
      state = RESTORE_CALIBRATION;
      shouldDoWarmupCalibration = false;
    }
    closePreferences();
  }

}

void loop() {

  long currentTime = millis();
  if (state == RESTORE_CALIBRATION) {
    if (currentTime - startTime > infoMsgDelay) {
      state = MEASURING;
    }
  } else if (shouldDoWarmupCalibration) {
    if (currentTime - startTime < warmupDelayInMs) {
      countdown = int((warmupDelayInMs - currentTime + startTime) / 1000) + 1;
      state = CALIBRATION_AIR_WARMUP;
    } else {
      // warmup is over, trigger calibration & skip warmup check in the future
      shouldDoWarmupCalibration = false;
      calibrationA.oxygenLevel = airCalibrationValue;
      updateCalibrationPointVoltage(calibrationA);
      oxygenVoltageAtLaunch = calibrationA.voltage;
      updateCalibration();
      state = MEASURING;
    }
  }

  // update sensor values
  updateFlowRate();
  updateOxygenLevel();


  // negative flow will trigger calibration of the non-ambient oxygen level
  if (state != CALIBRATION_AIR_WARMUP && state != RESTORE_CALIBRATION) {
    handleNegativeFlow();
  }

  displayState();

  delay(300);
}

void handleNegativeFlow() {
  if (diffPressure < 0 && abs(diffPressure) >= minAbsDiffPressure) {
    // negative flow rate detected
    long currentTime = millis();

    if (negativeFlowStartTime == 0) {
      // negative flow starting
      negativeFlowStartTime = currentTime;
    }
    int timeDif = currentTime - negativeFlowStartTime;

    // wait for init delay to trigger negative flow action
    unsigned long relevantDelay = negativeFlowInitDelayInMs;
    if (timeDif > relevantDelay) {

      // negative flow calibration

      // check if warmup is finished
      relevantDelay += calibrateNegativeFlowWarmupInMs;
      if(timeDif < relevantDelay) {
        state = CALIBRATION_NEGFLOW_WARMUP;
      } else {
        // check if calibration already happened, if not, calibrate and reset flash
        if(state == CALIBRATION_NEGFLOW_WARMUP) {
          calibrateToNegativeFlow();
          resetCalibrationInFlash();
          state = CALIBRATION_NEGFLOW_DONE;
        }

        // wait until "calibration done" message was displayed
        relevantDelay += infoMsgDelay;
        if (timeDif > relevantDelay) {

          // delay to confirm that the calibration should be permanently stored
          relevantDelay += negativeFlowPermanentSaveDelayInMs;
          if(timeDif < relevantDelay) {
            state = CALIBRATION_NEGFLOW_SAVE_DELAY;
          } else {
            // store calibration once
            if(state == CALIBRATION_NEGFLOW_SAVE_DELAY) {
              storeCalibrationToFlash();
              state = CALIBRATION_NEGFLOW_SAVED;
            }
          }
        }
      }
    }
    countdown = int((relevantDelay - timeDif) / 1000) + 1;
  } else {
    negativeFlowStartTime = 0;
  }
}

boolean openPreferences(boolean readOnly) {
  boolean success = prefs.begin(prefsDevice, readOnly);
  if (!success) Serial.println("failed to initialise NVS-Namespace");
  return success;
}

void closePreferences() {
  prefs.end();
}

void displayState() {
  String line1 = "  Open Oxygen   ";
  String line2 = "                ";

  if (state == LAUNCH) {
    line2 = "Launching..     ";
  }
  else if(state == CALIBRATION_AIR_WARMUP) {
    line1 = "Calibr. to ";
    line1 = line1 + String(airCalibrationValue, 1) + "%      ";
    line2 = "in ";
    line2 = line2 + countdown + "s, raw: " + adc0 * adcToMV + "        ";
  }
  else if (state == RESTORE_CALIBRATION) {
    line2 = "Restoring calibration..   ";
  }
  else if (state == MEASURING) {
    line1 = F("Flow: ");
    line1 += String(flowRate, 5) + "     ";
    line2 = F("Oxygen: ");
    line2 += String(oxygenLevel, 4) + "     ";
  }
  else if(state == CALIBRATION_NEGFLOW_WARMUP) {
    line1 = "Calibr. to ";
    line1 = line1 + String(negativeFlowCalibrationValue, 1) + "%     ";
    line2 = "in ";
    line2 = line2 + countdown + "s, raw: " + adc0 * adcToMV + "        ";
  }
  else if(state == CALIBRATION_NEGFLOW_DONE) {
    line1 = "Calibration to  ";
    line2 = "% O2 done.   ";
    line2 = String(negativeFlowCalibrationValue, 1) + line2;

  }
  else if(state == CALIBRATION_NEGFLOW_SAVE_DELAY) {
    line1 = "Saving calibr.  ";
    line2 = "perm. in ";
    line2 = line2 + countdown + "s..  ";
  }
  else if(state == CALIBRATION_NEGFLOW_SAVED) {
    line1 = "Calibr. to ";
    line1 = line1 + String(negativeFlowCalibrationValue, 1) + "%     ";
    line2 = "perm. saved.    ";
  }

  line1 = line1.substring(0, 16);
  line2 = line2.substring(0, 16);
  lcd.setCursor(0, 0);
  lcd.print(line1);
  lcd.setCursor(0, 1);
  lcd.print(line2);
}

void updateFlowRate() {
  float temperature; // Storage for the temperature

  // Read the averaged differential pressure and temperature from the sensor
  mySensor.readMeasurement(&diffPressure, &temperature); // Read the measurement

  // convert the differential pressure into flow-rate
  flowRate = convert2slm(abs((float)diffPressure));

  Serial.print(F("Differential pressure is: "));
  Serial.print(diffPressure, 2);
  Serial.print(F(" (Pa);  Flow-rate: "));
  Serial.print(flowRate);
  Serial.println(F(" (slm)"));
}

void updateCalibrationPointVoltage(CalibrationPoint calibrationPoint) {
  float adcMean = 0; // we should do an average over many samples here
  for (int imeas = 0; imeas < 10; imeas++) {
    adc0 = ads.getLastConversionResults();
    adcMean += adc0;
  }
  adcMean = adcMean / 10;
  calibrationPoint.voltage = adcMean*adcToMV;
}

void updateCalibration() {
  oxy_m = (adcToMV * (calibrationA.voltage - calibrationB.voltage)) / (calibrationA.oxygenLevel - calibrationB.oxygenLevel);
  oxy_b = calibrationA.oxygenLevel - calibrationA.voltage*oxy_m;
  Serial.println("Update calibration using these points:");
  Serial.print("A: ");
  Serial.print(calibrationA.oxygenLevel);
  Serial.print("%, ");
  Serial.print(calibrationA.voltage);
  Serial.println("mV");
  Serial.print("B: ");
  Serial.print(calibrationB.oxygenLevel);
  Serial.print("%, ");
  Serial.print(calibrationB.voltage);
  Serial.println("mV");
  Serial.print("oxy_m: ");
  Serial.print(oxy_m);
  Serial.print(" oxy_b: ");
  Serial.println(oxy_b);
}


void updateOxygenLevel() {
  adc0 = ads.getLastConversionResults();
  //Serial.print("AIN0: "); Serial.println(adc0);
  // http://cool-web.de/esp8266-esp32/ads1115-16bit-adc-am-esp32-voltmeter.htm
  oxygenLevel = adc0 * adcToMV * oxy_m + oxy_b;
  Serial.print("Oxygenlevel: "); Serial.print(oxygenLevel); Serial.println(" %");
  Serial.print("ADC: "); 
  Serial.println(adc0);
}

void calibrateToNegativeFlow() {
    calibrationB.oxygenLevel = negativeFlowCalibrationValue;
    updateCalibrationPointVoltage(calibrationB);
    updateCalibration();
}

void storeCalibrationToFlash() {
  Serial.println("Writing calibration to flash:");
  if(openPreferences(false)) {
    prefs.putFloat(prefsM, oxy_m);
    prefs.putFloat(prefsB, oxy_b);
    Serial.print("Reading initial oxy_m value from flash: ");
    Serial.println(prefs.getFloat(prefsM, 0));
    Serial.print("Reading initial oxy_b value from flash: ");
    Serial.println(prefs.getFloat(prefsB, 0));
    closePreferences(); 
  }
}

void resetCalibrationInFlash() {
  Serial.println("Resetting oxy_m in flash..");
  if(openPreferences(false)) {
    prefs.remove(prefsM);
    prefs.remove(prefsB);
    Serial.print("Reading initial oxy_m value from flash: ");
    Serial.println(prefs.getFloat(prefsM, 0));
    Serial.print("Reading initial oxy_b value from flash: ");
    Serial.println(prefs.getFloat(prefsB, 0));
    closePreferences(); 
  }
}

float convert2slm(float dp) {
  // convert the differential presure dp into the standard liter per minute
  float a = -20.04843438;
  float b = 59.52168936;
  float c = 3.11050553;
  float d = 10.35186327;
  return a + sqrt(b + dp * d) * c;
}

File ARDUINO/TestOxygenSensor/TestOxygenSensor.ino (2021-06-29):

#include <Wire.h>
#include <Adafruit_ADS1X15.h>

 Adafruit_ADS1115 ads;  /* Use this for the 16-bit version */
//Adafruit_ADS1015 ads;     /* Use thi for the 12-bit version */

void setup(void) 
{
  Serial.begin(115200);
  Serial.println("Hello!");
  
  Serial.println("Single-ended readings from AIN0 with >3.0V comparator");
  Serial.println("ADC Range: +/- 6.144V (1 bit = 3mV/ADS1015, 0.1875mV/ADS1115)");
  Serial.println("Comparator Threshold: 1000 (3.000V)");
  
  // The ADC input range (or gain) can be changed via the following
  // functions, but be careful never to exceed VDD +0.3V max, or to
  // exceed the upper and lower limits if you adjust the input range!
  // Setting these values incorrectly may destroy your ADC!
  //                                                                ADS1015  ADS1115
  //                                                                -------  -------
  ads.setGain(GAIN_TWOTHIRDS);  // 2/3x gain +/- 6.144V  1 bit = 3mV      0.1875mV (default)
  // ads.setGain(GAIN_ONE);        // 1x gain   +/- 4.096V  1 bit = 2mV      0.125mV
  // ads.setGain(GAIN_TWO);        // 2x gain   +/- 2.048V  1 bit = 1mV      0.0625mV
  // ads.setGain(GAIN_FOUR);       // 4x gain   +/- 1.024V  1 bit = 0.5mV    0.03125mV
  // ads.setGain(GAIN_EIGHT);      // 8x gain   +/- 0.512V  1 bit = 0.25mV   0.015625mV
  // ads.setGain(GAIN_SIXTEEN);    // 16x gain  +/- 0.256V  1 bit = 0.125mV  0.0078125mV
  
  ads.begin();
  
  // Setup 3V comparator on channel 0
  ads.startComparator_SingleEnded(0, 1000);
}

void loop(void) 
{
  int16_t adc0;
  int16_t mv=0;
  
  // Comparator will only de-assert after a read
  adc0 = ads.getLastConversionResults();
  //Serial.print("AIN0: "); Serial.println(adc0);
  mv = adc0 * 0.1875;
  Serial.print(mv); Serial.println(" mV");
  
  delay(500);
}

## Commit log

2021-06-01 Update README.md
    Adding proper links and prices to the BOM
2021-06-01 Updating the CAD Files for Inventor 2019
    [00_Arduino_LCD_I2Cstep.ipt, 00_Arduino_LCD_I2Cstep.step, 00_ESP32.ipt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]
2021-06-03 Updating the 3D printed files for the first housed prototype.
    [00_Batterypack.ipt, 00_LM286.0001.ipt, 00_LM286.ipt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]
2021-06-05 Updating the CAD assembly
    [01_Connector_T.0003.ipt, 01_Connector_T.0004.ipt, 01_Connector_T.ipt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]
2021-06-06 Many updates on the documentation and CAD/printable parts
    [01_Connector_T.stl, 02_Connector_S.stl, 02_Connector_T.stl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]
2021-06-06 Updating README and INVENTOR files
    [02_Connector_S.0005.ipt, 02_Connector_S.0006.ipt, 02_Connector_S.ipt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]
2021-06-07 Adding Calibration Data for the Flow Sensor
    [FlowCalibrationData.csv]
2021-06-08 Updating documentation to match the new ADC board
2021-06-08 Updating the electronics chart with new ADC converter
2021-06-10 Integrating the I2C-based ADC for measuring Oxygen level into the Arduino code; Updating housing to better hold the Oxygen sensor.
    [02_Connector_S.0006.ipt, 02_Connector_S.0007.ipt, 02_Connector_S.ipt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]
2021-06-11 Update the Code to finally make it work; correct Tubing for better airflow
    [02_Connector_S.0007.ipt, 02_Connector_S.0009.ipt, 02_Connector_S.ipt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]
2021-06-11 OpenOxygenFlowMeter: add warmup and calibration phase
2021-06-13 Adding the lid to the STL files
    [03_Lid.stl]
2021-06-13 Updating the calibration values of the oxygen sensor
2021-06-13 Updating documentation for the Calibration part
    [Assemlby_OpenOxygen_02_03_Lid.stl]
2021-06-14 Disable calibration until it's fixed
    [OpenOxygenFlowMeter.ino]
2021-06-21 Calibrate to 20.9% after 10sec warmup
2021-06-28 OpenOxygenMeter: Add negative flow calibration routine
2021-06-29 Updating lid to better reflect the code for calibration routine
    - add symbols for calibration flow direction
    - need to make it more clear and add proper ASCII symbols
    [03_Lid.0002.ipt, 03_Lid.ipt, Assemlby_OpenOxygen.0014.iam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]
2021-06-29 Updating the Arduino sketch
    - Add option to calibrate with O2 or N2
    - Make use of updating m and b for mx+b
    - library for ADC does not work on Windows (please change if necessary!!)
    - The mx+b update needs a review!!
    [OpenOxygenFlowMeter.ino]
2021-07-01 OpenOxygenFlowMeter: Add missing semicolon
    [OpenOxygenFlowMeter.ino]
2021-07-01 OpenOxygenFlowMeter: improve calibration
    - add ability to use negative flow to calibrate to any O2 concentration
    point, use air O2 concentration point at launch as second calibration
    point
